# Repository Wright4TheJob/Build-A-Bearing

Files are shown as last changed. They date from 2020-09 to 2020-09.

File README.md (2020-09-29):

# 3D Printable Ball Bearings
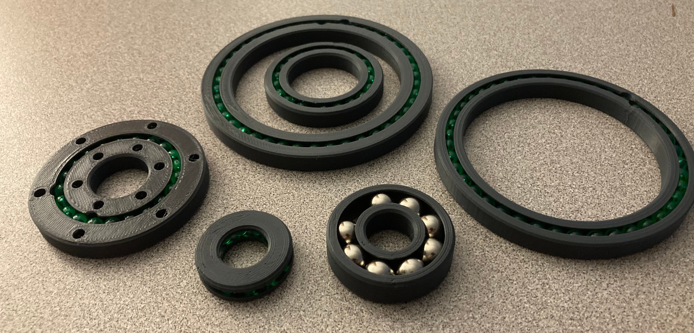
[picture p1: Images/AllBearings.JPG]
The bearings available in this repository

## The Problem
Many people have demonstrated 3D printing complete ball bearings using soluble support material or excellent material calibration. These bearings require clearance between the balls and the races to print separately and have low strength. In short, they are excellent demonstration pieces but do not function well as bearings.

## A Solution
3D printing races which can be filled with mass-manufactured balls creates relatively smooth-running bearings without requiring expensive materials or tooling, other than a 3D printer. In addition, these bearings can be made at larger sizes where industrial bearings are prohibitively expensive.

# The Project
This project holds fully parametric design files for a variety of types of 3D-print-ready bearings. These files can be modified to the size and shape you need and tuned to match your printer's capabilities. The bearings are modeled in @FreeCAD ([Official Website](https://www.freecadweb.org/)) and are licensed for you to use as you please on your next project.

# How to use this project
If you want to dive right in and try printing a bearing, [this is a simple and small one to start with](https://github.com/Wright4TheJob/Build-A-Bearing/blob/master/Ball%20Bearing/Plain/BallBearing2040.amf). It uses 6mm Airsoft BBs commonly available in sporting stores and does not add any compensation for additional clearance or pre-compression on the balls.

If you would rather test your printer's settings first, download the Clearance Test and tune the settings to match your printer's calibration.

A walkthrough of the settings for each bearing is available along with the design files. This includes overall dimensions of the bearing as well as clearances for your printers needs. The typical settings are shown below.

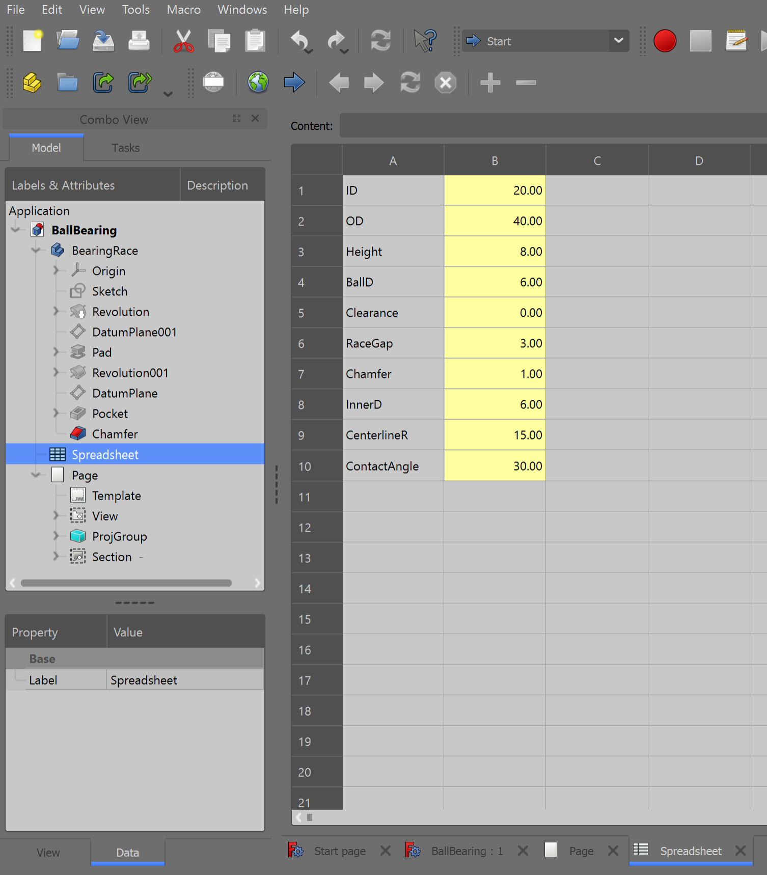
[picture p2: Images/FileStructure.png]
Spreadsheet for adjusting bearing settings


There are pre-exported files ready for slicing in common sizes for each type of bearing if you would rather use the pre-generated files. Files are named according to their type and size. The first two digits of the number are the inner diameter in millimeters, and the last two digits are the outer diameter in millimeters.

For assembly, all the bearings include a circular cut on the inner and outer races. After printing is complete, align these two cuts and insert the initial balls. Distribute the initial balls around the perimeter to hold the inner race in place while the rest of the balls are inserted. Future bearings may have a split inner race, held together with fasteners, to eliminate the cutout and have smoother operation. For quieter bearing operation, some lubrication may be helpful. Petroleum jelly has worked well for me at low speeds.

# Bearing Types
Ball Bearing:
Assortment of ball bearings

Flanged Ball Bearing:
Flanged ball bearing

Thrust Bearing:
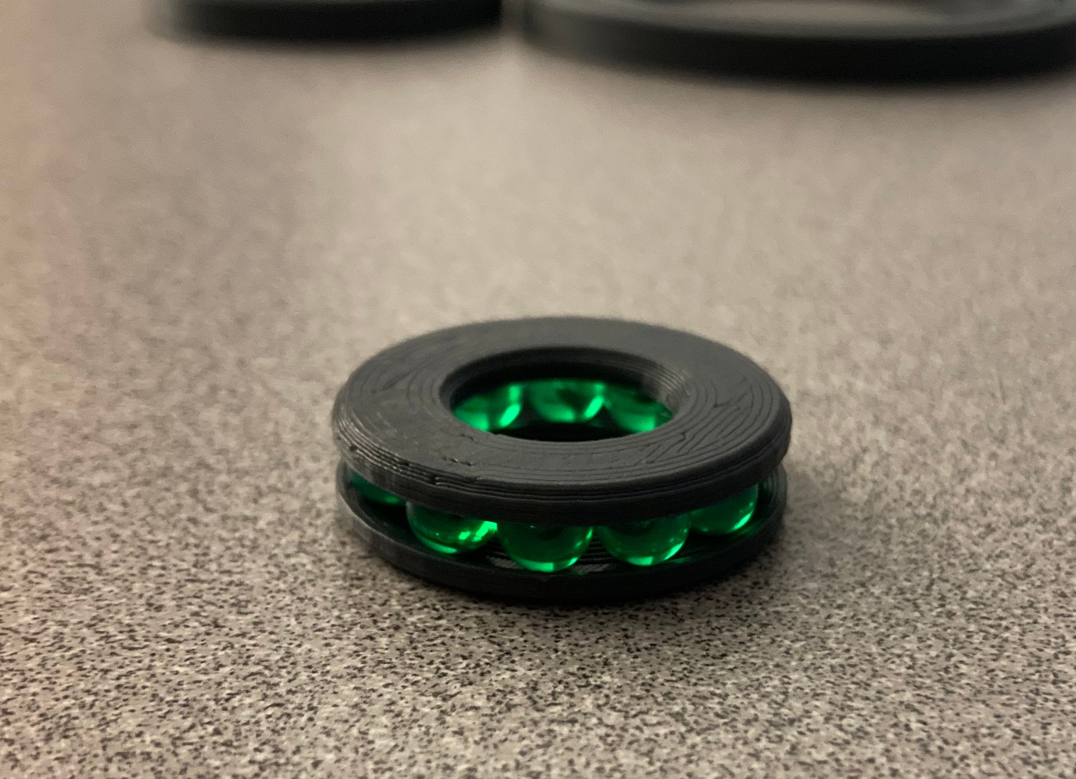
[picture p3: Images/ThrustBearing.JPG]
Thrust bearing


# How to contribute to this project
Implement more bearing designs! There are many cool bearings out there for specialized uses. Model them and submit a pull request, and we can add them to a growing library.

# Which bearing do I want?
1. Have reasonable expectations. These bearings are still mostly (or completely) plastic, so will not survive very high speeds or intense loads as well as industrial bearings. Bearing test data and recommended loading would be great to add to this one day.
2. You probably need a ball bearing. For most common applications, this is a good choice. Skateboard wheels, fidget spinners, or the scroll wheel on a high quality mouse all probably use ball bearings. However, if you want to get the most out of your design, using a more specialty bearing may help.
3. Is the bearing rotating constantly or doing positioning? The high load ball bearing distributes the contact between the ball and race along a curved surface which gives higher stiffness and load capacity at the expense of higher friction. If you have a robot arm that is moving back and forth or a rotating display table, this may be a good choice for you. If the bearing is rotating constantly or at higher speeds, the standard ball bearing is probably best.
4. Is the majority of the force the bearing is transmitting along the shaft going through the bearing (axial) or across the races of the bearing (radial)? If most or all of the load is transmitted axially, consider a thrust bearing. Rather than splitting the bearing into an outer and inner race, the thrust bearing splits like a sandwich, with a top and bottom race and balls between. Machines with high forces along the rotating shaft, like the leadscrew on the motion axis of a mill, often use thrust bearings to resist that force. Ball bearings can resist some axial load, but wear out more quickly.
5. Does your design have parts to place the bearings in (bearing housings) or do you need to attach the bearing another way? The flanged ball bearing can be bolted to the face of a part without needing a larger recess. In some cases, this can save space or make it easier to disassemble and service the machine.

# Future Improvements
- [ ] Split internal or external race for gapless design
- [ ] Internal or external gearing for driven bearing rotation.

# Acknowledgments
Many thanks to [Jeff Kerr](https://www.thingiverse.com/lobocnc/designs) for his design of a [robot actuator with integrated ball bearing](https://www.thingiverse.com/thing:3293562) for the inspiration for this design.

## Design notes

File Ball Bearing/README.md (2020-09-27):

## Printing Notes
Finer layer heights will result in a smoother race surface. Retraction settings can also be important to minimize blobs or lumps from perimeter starts and stops. A quick sanding also helps smooth out natural irregularities in the printed surface.

## Assembly Notes
Align the circular cuts on the inner and outer races to insert the first balls. Distribute the balls evenly around the races to hold everything in place as you continue to add more. 

## Application Notes
The flanged ball bearing can be used to join two sections together without needing additional bearing retention components.

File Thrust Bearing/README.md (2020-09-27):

## Printing Notes

The model for the thrust bearing includes only one race for easy printing.

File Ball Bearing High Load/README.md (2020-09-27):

## Printing Notes
The circular profile of the insides of the bearings races make contact with the ball over a larger area. This increases load capacity of the bearing but adds friction because not all the points on the ball roll at the same speed. This also leads to a generally tighter fit than the standard ball bearing, so consider increasing clearances by a bit (I added 0.1mm) compared with your settings for the ball bearing.

## Assembly
Align the gaps in the races and add balls one at a time. To prevent balls from falling out, use a narrow tool to space the balls out around the race and hold the inner and outer races together while the rest of the balls are added. Leave a about one ball's worth of gap so that the balls are not squeezed against their neighbors, since this also increases friction.

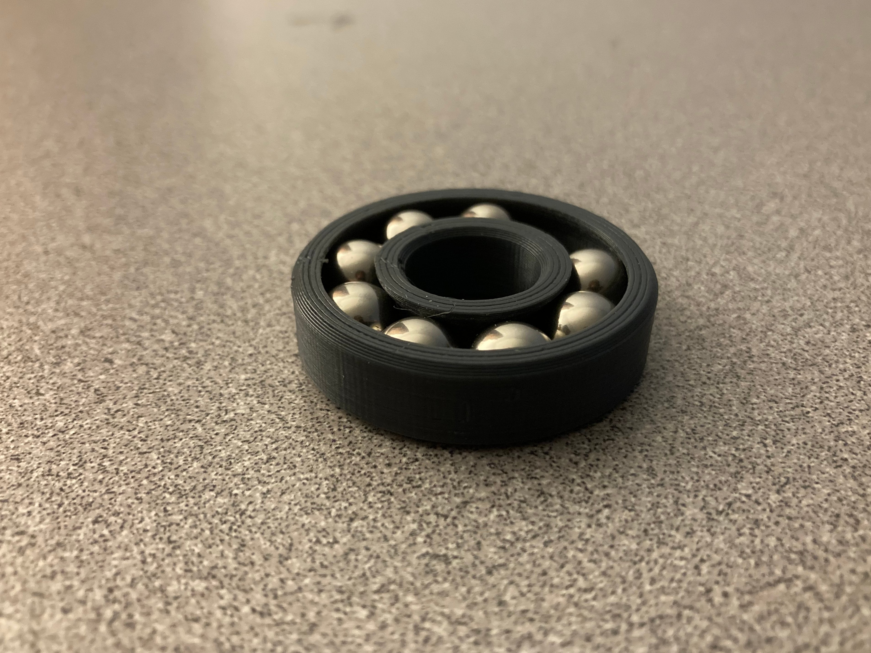
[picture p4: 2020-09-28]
Images/BallBearingMetal.JPG

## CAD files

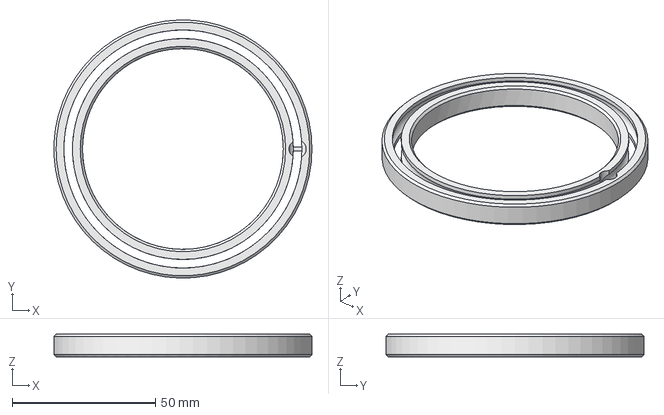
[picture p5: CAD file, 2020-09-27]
Ball Bearing High Load/Ball Bearing High Load.FCStd
89.9 x 90.0 x 8.00 mm
BearingRace x 2

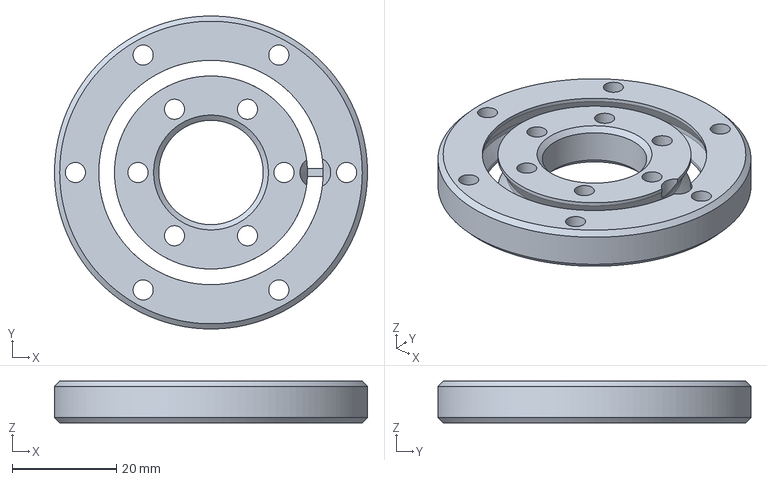
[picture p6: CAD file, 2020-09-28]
Ball Bearing/Flanged/FlangedBearing2060.amf
60.0 x 60.0 x 8.00 mm

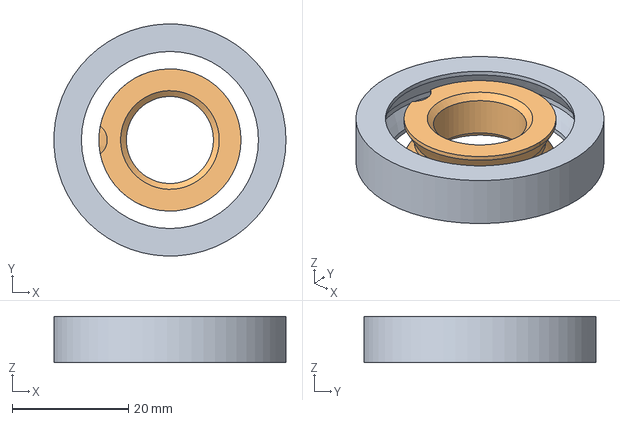
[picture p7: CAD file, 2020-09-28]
Ball Bearing/Plain/BallBearing.FCStd
40.0 x 40.0 x 8.00 mm
OuterRace
InnerRace

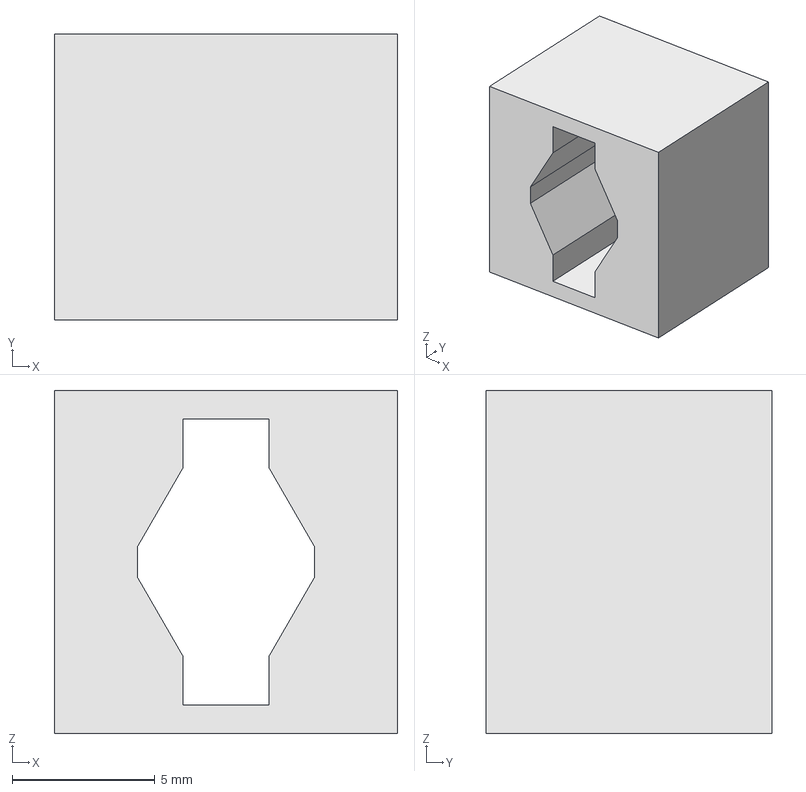
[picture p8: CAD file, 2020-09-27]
Clearance Test/ClearanceTest.FCStd
12.0 x 10.0 x 12.0 mm

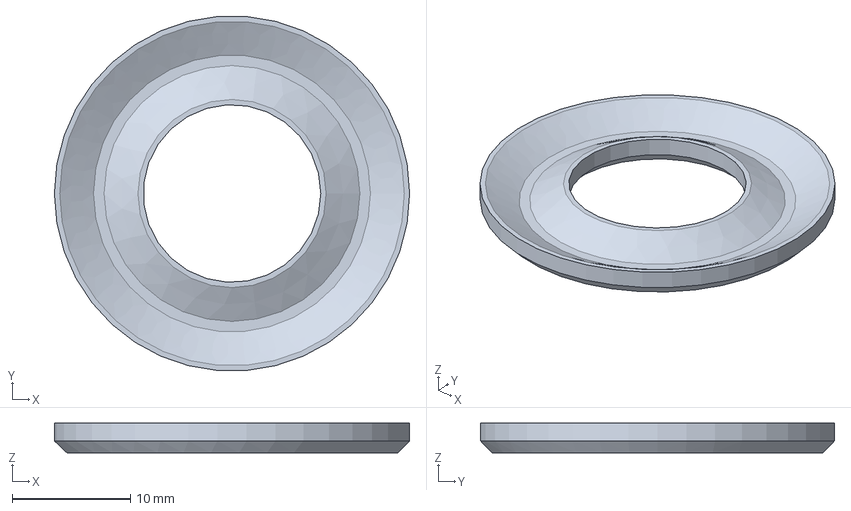
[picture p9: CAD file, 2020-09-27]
Thrust Bearing/ThrustBearing3020.amf
30.0 x 29.9 x 2.50 mm

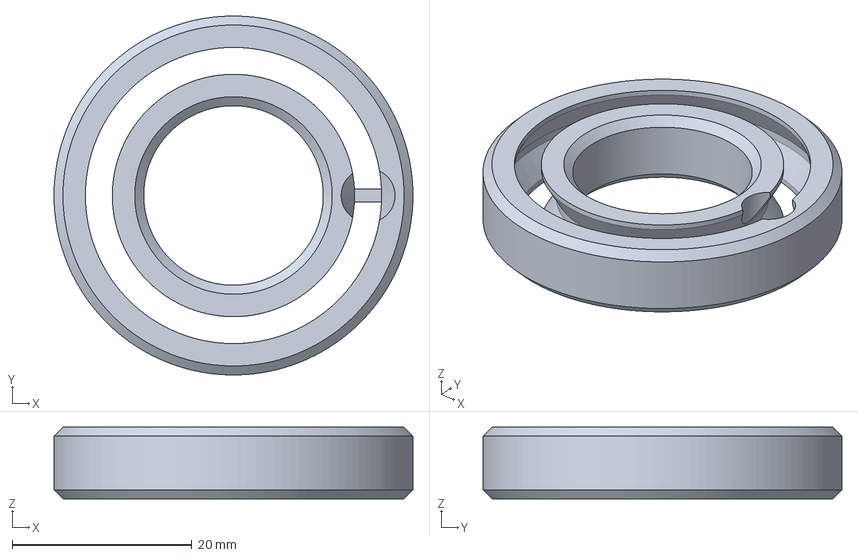
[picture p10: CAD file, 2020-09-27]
Ball Bearing/Plain/BallBearing2040.amf
40.0 x 40.0 x 8.00 mm

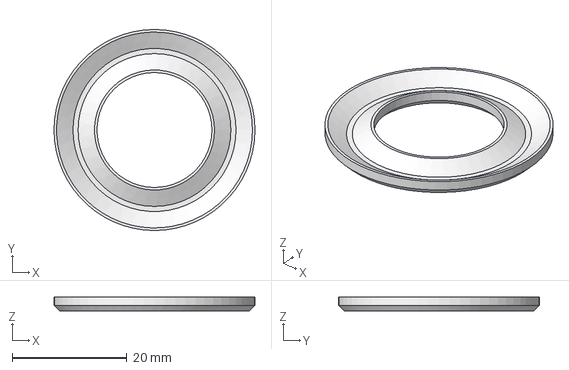
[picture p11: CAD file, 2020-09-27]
Thrust Bearing/Thrust Ball Bearing.FCStd
35.0 x 35.0 x 2.50 mm

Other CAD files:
Ball Bearing/Flanged/Ball Bearing Flanged.FCStd
Clearance Test/ClearanceTest.amf

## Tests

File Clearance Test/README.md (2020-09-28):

## Printing Notes
Print this sample part as shown below to most accurately represent how your printer will handle printing bearing races.

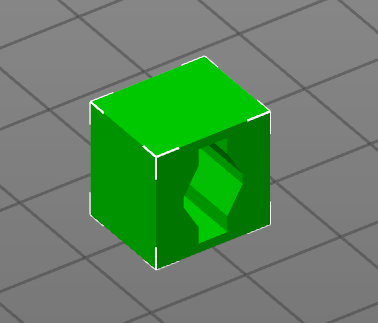
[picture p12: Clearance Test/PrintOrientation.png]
Test oriented with hole horizontal on print bed


Just like the bearings, the clearances and ball size can all be adjusted from the internal spreadsheet. Remember that the bearing races may allow more flex than this test piece, since the bearing races are not joined together. To avoid having rattle in your bearing, it is better to have this test fit tightly.

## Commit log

2020-09-27 Modified Ball Bearing file and added starter bearing print file.
    [BallBearing.FCStd, BallBearing2040.amf]
2020-09-28 Added images.
    [Ball Bearing Flanged.FCStd, FlangedBearing2060.amf]
2020-09-28 Updated design tree for greater resiliancy.
    [BallBearing.FCStd]
2020-09-29 Update assembly walkthrough.
